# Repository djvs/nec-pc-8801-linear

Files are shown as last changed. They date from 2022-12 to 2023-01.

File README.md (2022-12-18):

# necpc8801linear

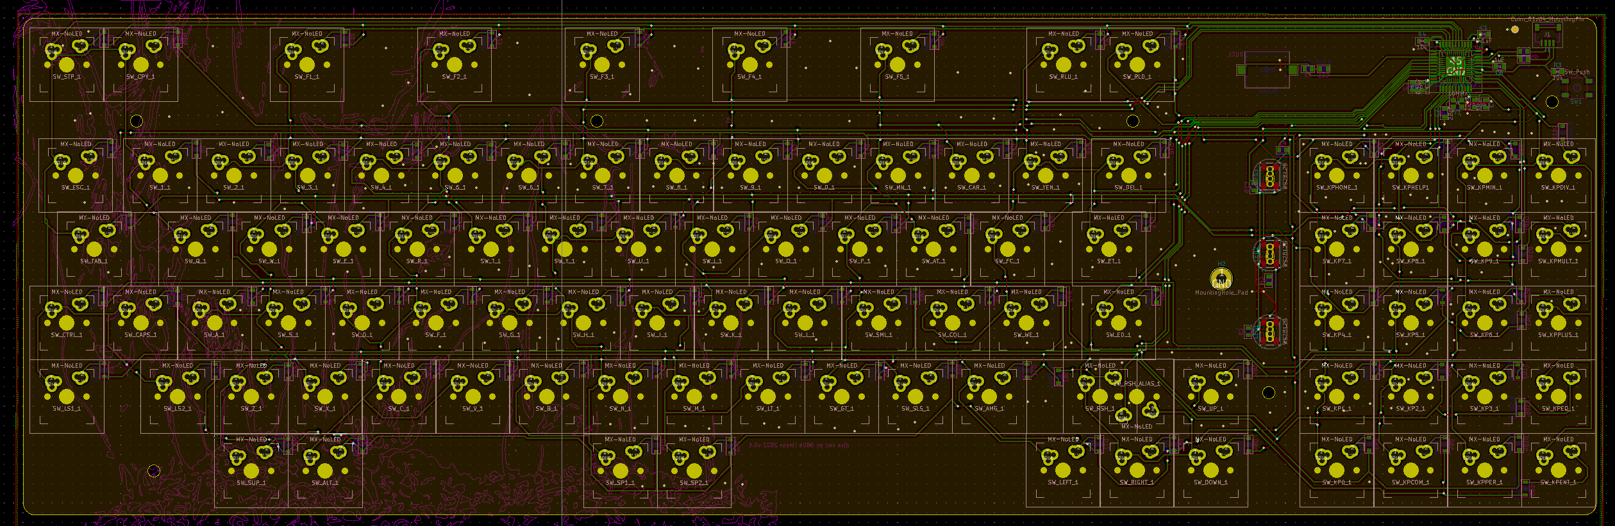
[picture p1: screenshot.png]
Screenshot of PCB


USB/QMK atmega32u4 pcb for NEC PC 8801 (NEC vintage linear and possibly equivalent SMK) with added MX and Alps support.  Also with WS2812B addressable LED & buzzer support.  

Released without warranty, use at your own risk.  Check your layout carefully too.

PRs & feedback welcome!

---

Dimensions: 405mm x 135.5mm

---

Shield: [][cc-by-sa]

This work is licensed under a
[Creative Commons Attribution-ShareAlike 4.0 International License][cc-by-sa].

[][cc-by-sa]

[cc-by-sa]: http://creativecommons.org/licenses/by-sa/4.0/
[cc-by-sa-image]: https://licensebuttons.net/l/by-sa/4.0/88x31.png
[cc-by-sa-shield]: https://img.shields.io/badge/License-CC%20BY--SA%204.0-lightgrey.svg

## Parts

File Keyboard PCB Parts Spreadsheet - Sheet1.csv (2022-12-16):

Part Name | Part Type | Value | Footprint | Digikey Part Num. | LCSC Part Num. | JLCSMT Type | Other Notes
nSMD050-24V | PTC Resettable Fuse | 500mA | 1206 |  | C70076 | Extended
1206L050/15YR | Polyfuse | 500mA Hold / 1A Trip | 1206 |  | C151162 | Extended | The fuse listed in the tutorial doesn't appear to be available, but this one is.
0603WAF220JT5E | Resistor | 22 | 0603 |  | C23345 | Basic
0603WAF1001T5E | Resistor | 1k | 0603 |  | C21191 | Basic
0603WAF5101T5E | Resistor | 5.1k | 0603 |  | C23186 | Basic
0603WAF1002T5E | Resistor | 10k | 0603 |  | C25804 | Basic
0603WAF3302T5E | Resistor | 33k | 0603 |  | C4216 | Basic
0603WAF1003T5E | Resistor | 100k | 0603 |  | C25803 | Basic
0603WAF1004T5E | Resistor | 1M | 0603 |  | C22935 | Basic
CL10C220JB8NNNC | Capacitor, Ceramic | 22pF | 0603 |  | C1653 | Basic
0603B472K500NT | Capacitor, Ceramic | 4.7nF | 0603 |  | C53987 | Basic
CC0603KRX7R9BB104 | Capacitor, Ceramic | 0.1uF | 0603 |  | C14663 | Basic
CL10A105KB8NNNC | Capacitor, Ceramic | 1uF | 0603 |  | C15849 | Basic
CL10A475KO8NNNC | Capacitor, Ceramic | 4.7uF | 0603 |  | C19666 | Basic
CL10A106KP8NNNC | Capacitor, Ceramic | 10uF | 0603 |  | C19702 | Basic
CL10A226MQ8NRNC | Capacitor, Ceramic | 22uF | 0603 |  | C59461 | Basic
0603WAF4701T5E | Resistor | 4.7k | 0603 |  | C23162 | Basic
0805W8F220JT5E | Resistor | 22 | 0805 |  | C17561 | Basic
0805W8F1001T5E | Resistor | 1k | 0805 |  | C17513 | Basic
0805W8F5101T5E | Resistor | 5.1k | 0805 |  | C27834 | Basic
0805W8F1002T5E | Resistor | 10k | 0805 |  | C17414 | Basic
0805W8F3302T5E | Resistor | 33k | 0805 |  | C17633 | Basic
0805W8F1003T5E | Resistor | 100k | 0805 |  | C17407 | Basic
0805W8F1004T5E | Resistor | 1M | 0805 |  | C17514 | Basic
CL21C220JBANNNC | Capacitor, Ceramic | 22pF | 0805 |  | C1804 | Basic
0805B472K500NT | Capacitor, Ceramic | 4.7nF | 0805 |  | C1744 | Basic
CC0805KRX7R9BB104 | Capacitor, Ceramic | 0.1uF | 0805 |  | C49678 | Basic
CL21B105KBFNNNE | Capacitor, Ceramic | 1uF | 0805 |  | C28323 | Basic
CL21A475KAQNNNE | Capacitor, Ceramic | 4.7uF | 0805 |  | C1779 | Basic
CL21A106KAYNNNE | Capacitor, Ceramic | 10uF | 0805 |  | C15850 | Basic
CL21A226MAQNNNE | Capacitor, Ceramic | 22uF | 0805 |  | C45783 | Basic
0805W8F4701T5E | Resistor | 4.7k | 0805 |  | C17673 | Basic | Used by split boards w/ QMK
PJ-320A | TRRS Connector, 3.5mm, THT |  | 3.5-4P |  | --- | Unavailable | Many colors available on Taobao
ATMEGA32U2-AU | Microcontroller | AVR | 32-TQFP (7x7) | ATMEGA32U2-AU-ND | C618733 | Unavailable
ATMEGA32U2-MU | Microcontroller | AVR | 32-VQFN (5x5) | ATMEGA32U2-MU-ND | C57345 | Extended
X322516MLB4SI | Crystal Oscillator | 16MHz | 3225 |  | C13738 | Basic
TS-1186D-C-A | Push Button |  | 4.70mm x 3.50mm |  | C397351 | Unavailable | Side-actuated tactile switch
ATMEGA32U4-AU | Microcontroller | AVR | 44-TQFP (10x10) | ATMEGA32U4-AU-ND | C44854 | Extended
ATMEGA32U4-MU | Microcontroller | AVR | 44-VQFN (7x7) | ATMEGA32U4-MU-ND | C112161 | Extended
STM32F072CBT6 | Microcontroller | ARM/STM32 | 48-LQFP (7x7) | 497-14645-ND | C81720 | Extended
STM32F072CBU6 | Microcontroller | ARM/STM32 | 48-UFQFPN (7x7) | 497-14646-ND | C92504 | Extended
TS-1187A-B-A-B | Push Button |  | 5.1 x 5.1 MM |  | C318884 | Extended
TAJB107K006RNJ | Capacitor, Tantalum | 100uF | CASE-B / 3528 |  | C16133 | Basic
EC11K1525413 | Encoder |  | EC11E |  | C470752 | Unavailable | "Best" normal encoder with detents
EC11E1834403 | Encoder |  | EC11E |  | C361165 | Unavailable | Highest pulse EC11E w/o detents, 1.5mm switch
EC11E15244B2 | Encoder |  | EC11E |  |  | Unavailable | 30 detent (highest reliable) EC11E, 1.5mm switch
TYPE-C-31-M-12 | USB-C |  | HRO-TYPE-C-31-M-12 |  | C165948 | Unavailable | Cheap popular easy to solder USB 2.0 USB-C connector, even cheaper clones available in bulk from aliexpress at around 15c/each, shipped, https://www.aliexpress.com/item/4000259156096.html
TYPE-C-31-M-13 | USB-C |  | HRO-TYPE-C-31-M-13 |  | C223906 | Unavailable | mid-mount version of M-12
TYPE-C-31-M-14 | USB-C |  | HRO-TYPE-C-31-M-14 |  | C223907 | Unavailable | Mid mount version USB-C - Used on the unsplit
DY-S352818/RGBC/6812-2T | LED |  | SK6812 Mini-E |  | C524051 | Unavailable | Tested and seems to work same as a SK6812 Mini-E
SM4007PL | Diode, Standard |  | SOD-123 |  | C64898 | Basic | cheapest diode on jlcpcb, price fluctuates but <$0.004 (at 200+) each
1N4148W | Diode, Standard |  | SOD-123 |  | C81598 | Basic | Common diode
RB060M-60 | Schottky Barrier Diode |  | SOD-123 |  | C115330 | Extended
SMF9.0CA | Bidirectional TVS Diode | 9V Breakdown | SOD-123 |  | C123799 | Extended
SMF6.0CA | Bidirectional TVS Diode | 6V Breakdown | SOD-123 |  | C123791 | Extended
UET14A05L03 | ESD Protection IC |  | SOT-143 |  | C78442 | Extended | Equivalent to PRTR5V0U2X but available as extended part for assembly
PRTR5V0U2X,215 | ESD Protection IC |  | SOT-143B | 1727-3884-2-ND | C12333 | Unavailable | USB data line ESD protection
XC6206P332MR | LDO | 3.3V | SOT-23 |  | C5446 | Basic | 3.3v 200mA LDO stable with ceramic caps and basic JLC part https://datasheet.lcsc.com/szlcsc/1809201513_Torex-Semicon-XC6206P332MR_C5446.pdf
DTC123JKAT146 | Transistor, NPN, Pre-Biased | DTC123J | SOT-23 |  | C111724 | Extended
AO3400A | MOSFET, N-Channel | 30V 5.7A | SOT-23 |  | C347475 | Extended
BSS138LT1G | MOSFET, N-Channel | 50V 200mA | SOT-23 |  | C82045 | Extended | Often used for level shifting
AO3400A | MOSFET, N-Channel | 30V 5.7A | SOT-23-3L |  | C20917 | Basic
SRV05-4-P-T7 | ESD Protection IC | 4 I/Os | SOT-23-6 |  | C85364 | Basic | basic part esd protection for usb https://datasheet.lcsc.com/szlcsc/1809192313_ProTek-Devices-SRV05-4-P-T7_C85364.pdf

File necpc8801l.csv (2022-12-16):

Id | Designator | Footprint | Quantity | Designation | Supplier and ref
1 | SW_Z_1,SW_Y_1,SW_YEN_1,SW_X_1,SW_W_1,SW_WE_1,SW_V_1,SW_U_1,SW_UP_1,SW_T_1,SW_TAB_1,SW_S_1,SW_SUP_1,SW_STP_1,SW_SP2_1,SW_SP1_1,SW_SMI_1,SW_SLS_1,SW_R_1,SW_RSH_ALIAS_1,SW_RSH_1,SW_RLU_1,SW_RLD_1,SW_RIGHT_1,SW_Q_1,SW_P_1,SW_O_1,SW_N_1,SW_M_1,SW_MN_1,SW_L_1,SW_LT_1,SW_LS2_1,SW_LS1_1,SW_LEFT_1,SW_K_1,SW_KPPLUS_1,SW_KPPER_1,SW_KPMULT_1,SW_KPMIN_1,SW_KPHOME_1,SW_KPHELP1,SW_KPEQ_1,SW_KPENT_1,SW_KPDIV_1,SW_KPCOM_1,SW_KP9_1,SW_KP8_1,SW_KP7_1,SW_KP6_1,SW_KP5_1,SW_KP4_1,SW_KP3_1,SW_KP2_1,SW_KP1_1,SW_KP0_1,SW_J_1,SW_I_1,SW_H_1,SW_G_1,SW_GT_1,SW_F_1,SW_FC_1,SW_F5_1,SW_F4_1,SW_F3_1,SW_F2_1,SW_F1_1,SW_E_1,SW_ET_1,SW_ESC_1,SW_ED_1,SW_D_1,SW_DOWN_1,SW_DEL_1,SW_C_1,SW_CTRL_1,SW_CPY_1,SW_COL_1,SW_CAR_1,SW_CAPS_1,SW_B_1,SW_A_1,SW_AT_1,SW_AMG_1,SW_ALT_1,SW_9_1,SW_8_1,SW_7_1,SW_6_1,SW_5_1,SW_4_1,SW_3_1,SW_2_1,SW_1_1,SW_0_1 | mx-nec-alps | 96 | MX-NoLED
2 | LED1,LED2,LED3 | WS2812BDual | 3 | WS2812B
3 | H2 | MountingHole_2.7mm_M2.5_Pad | 1 | MountingHole_Pad
4 | SW1 | SKQG-1155865 | 1 | SW_Push
5 | D16,D1,D2,D3,D4,D5,D6,D7,D8,D9,D10,D12,D13,D14,D15,D17,D18,D19,D20,D21,D23,D24,D25,D26,D27,D28,D29,D30,D31,D32,D34,D35,D36,D37,D38,D39,D40,D41,D42,D44,D45,D46,D47,D48,D49,D50,D51,D52,D53,D54,D56,D57,D58,D59,D60,D61,D62,D63,D64,D65,D67,D68,D69,D70,D71,D72,D73,D75,D76,D78,D81,D82,D83,D84,D85,D89,D90,D91,D92,D93,D94,D95,D96,D97,D99,D101,D102,D103,D104,D109,D110,D98,D106,D105,D43 | D_SOD-123 | 95 | D_Small
6 | C8,C9,C10,C1,C2,C5,C11 | C_0805_2012Metric | 7 | 0.1uF
7 | R1 | R_0805_2012Metric | 1 | 330
8 | C6 | C_0805_2012Metric | 1 | 1uF
9 | C7 | C_0805_2012Metric | 1 | 10uF
10 | J1 | JST_SH_SM04B-SRSS-TB_1x04-1MP_P1.00mm_Horizontal | 1 | Conn_01x04_MountingPin
11 | R3,R4 | R_0805_2012Metric | 2 | 10k
12 | U1 | atmega32u4-mu-and-au | 1 | ATmega32U4-MU
13 | Y1 | Crystal_SMD_3225-4Pin_3.2x2.5mm | 1 | 16MHz
14 | C3,C4 | C_0805_2012Metric | 2 | 22pF
15 | R5,R2,R6 | R_0805_2012Metric | 3 | 22
16 | BUZ1 | Buzzer_Mallory_AST1109MLTRQ | 1 | Buzzer

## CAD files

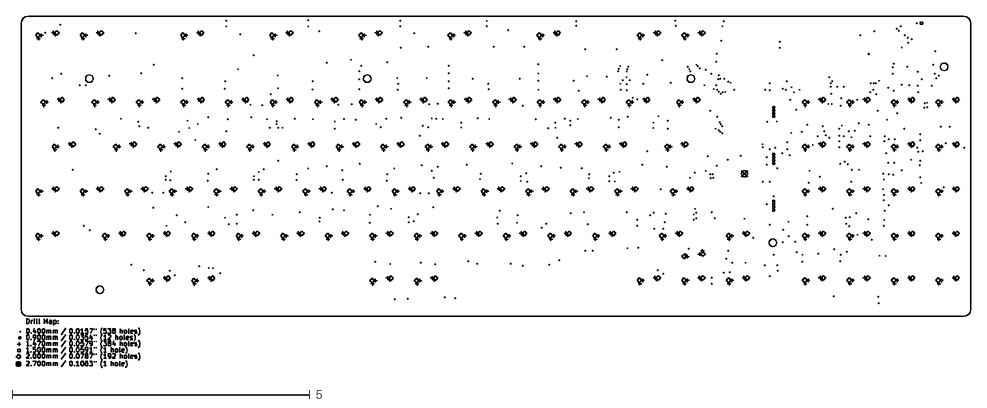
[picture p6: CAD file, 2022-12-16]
outputs/gerber/necpc8801l-PTH-drl_map.dxf
16.0 x 5.90

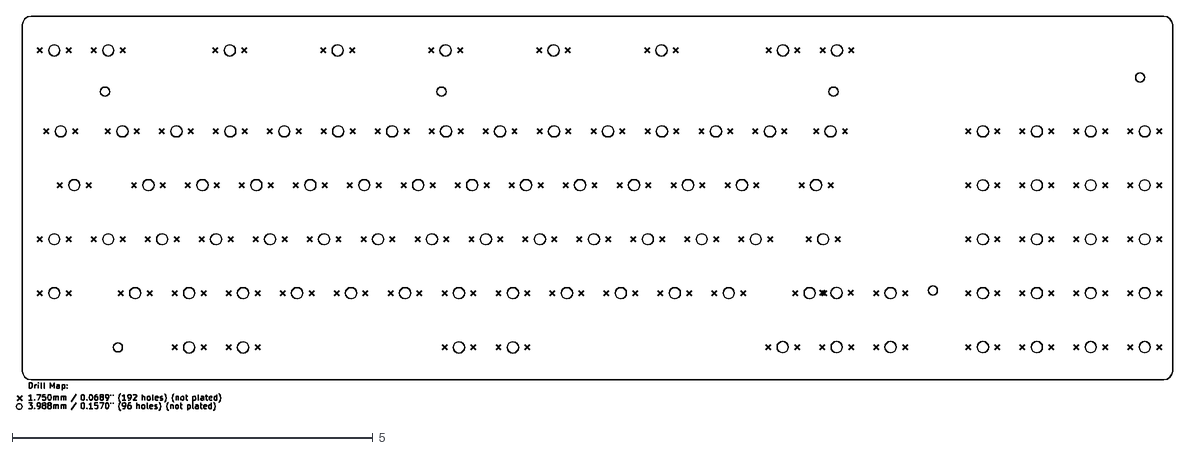
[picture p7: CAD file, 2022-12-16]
outputs/gerber/necpc8801l-NPTH-drl_map.dxf
16.0 x 5.47

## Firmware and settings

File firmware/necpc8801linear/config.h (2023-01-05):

/*
Copyright 2021 djvs

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
You should have received a copy of the GNU General Public License
along with this program.  If not, see <http://www.gnu.org/licenses/>.
*/

#pragma once

#include "config_common.h"

/* USB Device descriptor parameter */
#define VENDOR_ID 0x1209
#define PRODUCT_ID 0x9209
#define DEVICE_VER 0x0001
#define MANUFACTURER "djvs"
#define PRODUCT "necpc8801linear"

/* key matrix size */
#define MATRIX_ROWS 10
#define MATRIX_COLS 10
#define RGBLIGHT_LAYERS

#define AUDIO_PIN C6
/*
 * Keyboard Matrix Assignments
 *
 * Change this to how you wired your keyboard
 * COLS: AVR pins used for columns, left to right
 * ROWS: AVR pins used for rows, top to bottom
 * DIODE_DIRECTION: COL2ROW = COL = Anode (+), ROW = Cathode (-, marked on
 * diode) ROW2COL = ROW = Anode (+), COL = Cathode (-, marked on diode)
 *
 */
#define MATRIX_ROW_PINS \
  { F1, B3, B7, B5, D5, D3, D6, D1, D0, B2 }
#define MATRIX_COL_PINS \
  { F0, F4, F6, F7, F5, D7, B6, B4, D2, B0 }
#define UNUSED_PINS \
  { E6, C7, B1 }

/* COL2ROW, ROW2COL */
#define DIODE_DIRECTION COL2ROW

/*
 * Split Keyboard specific options, make sure you have 'SPLIT_KEYBOARD = yes' in
 * your rules.mk, and define SOFT_SERIAL_PIN.
 */
// #define SOFT_SERIAL_PIN D0  // or D1, D2, D3, E6

//#define LED_NUM_LOCK_PIN B0
//#define LED_CAPS_LOCK_PIN B1
//#define LED_SCROLL_LOCK_PIN B2
//#define LED_COMPOSE_PIN B3
//#define LED_KANA_PIN B4

//#define BACKLIGHT_PIN F4
//#define BACKLIGHT_CAPS_LOCK
//#define BACKLIGHT_DRIVER =
//#define BACKLIGHT_LEVELS 3
//#define BACKLIGHT_BREATHING

#define RGB_DI_PIN D4
#ifdef RGB_DI_PIN
#define RGBLED_NUM 3
#define RGBLIGHT_DEFAULT_MODE (RGBLIGHT_MODE_RAINBOW_SWIRL)

#define RGBLIGHT_DEFAULT_HUE 64
//#    define RGBLIGHT_DEFAULT_SAT 255
#define RGBLIGHT_DEFAULT_VAL 255
//#    define RGBLIGHT_HUE_STEP 8
//#    define RGBLIGHT_SAT_STEP 8
//#    define RGBLIGHT_VAL_STEP 8
//#    define RGBLIGHT_LIMIT_VAL 255 /* The maximum brightness level */
//#    define RGBLIGHT_SLEEP  /* If defined, the RGB lighting will be switched
//off when the host goes to sleep */
/*== all animations enable ==*/
#define RGBLIGHT_ANIMATIONS
/*== or choose animations ==*/
//#    define RGBLIGHT_EFFECT_BREATHING
//#    define RGBLIGHT_EFFECT_RAINBOW_MOOD
//#    define RGBLIGHT_EFFECT_RAINBOW_SWIRL
//#    define RGBLIGHT_EFFECT_SNAKE
//
//#    define RGBLIGHT_EFFECT_KNIGHT
//#    define RGBLIGHT_EFFECT_CHRISTMAS
//#    define RGBLIGHT_EFFECT_STATIC_GRADIENT
//#    define RGBLIGHT_EFFECT_RGB_TEST
//#    define RGBLIGHT_EFFECT_ALTERNATING
/*== customize breathing effect ==*/
/*==== (DEFAULT) use fixed table instead of exp() and sin() ====*/
//#    define RGBLIGHT_BREATHE_TABLE_SIZE 256      // 256(default) or 128 or 64
/*==== use exp() and sin() ====*/
//#    define RGBLIGHT_EFFECT_BREATHE_CENTER 1.85  // 1 to 2.7
//#    define RGBLIGHT_EFFECT_BREATHE_MAX    255   // 0 to 255
#endif

/* Debounce reduces chatter (unintended double-presses) - set 0 if debouncing is
 * not needed */
#define DEBOUNCE 5

/* define if matrix has ghost (lacks anti-ghosting diodes) */
//#define MATRIX_HAS_GHOST

/* Mechanical locking support. Use KC_LCAP, KC_LNUM or KC_LSCR instead in keymap
 */
#define LOCKING_SUPPORT_ENABLE
/* Locking resynchronize hack */
#define LOCKING_RESYNC_ENABLE

/* If defined, GRAVE_ESC will always act as ESC when CTRL is held.
 * This is useful for the Windows task manager shortcut (ctrl+shift+esc).
 */
//#define GRAVE_ESC_CTRL_OVERRIDE

/*
 * Force NKRO
 *
 * Force NKRO (nKey Rollover) to be enabled by default, regardless of the saved
 * state in the bootmagic EEPROM settings. (Note that NKRO must be enabled in
 * the makefile for this to work.)
 *
 * If forced on, NKRO can be disabled via magic key (default = LShift+RShift+N)
 * until the next keyboard reset.
 *
 * NKRO may prevent your keystrokes from being detected in the BIOS, but it is
 * fully operational during normal computer usage.
 *
 * For a less heavy-handed approach, enable NKRO via magic key (LShift+RShift+N)
 * or via bootmagic (hold SPACE+N while plugging in the keyboard). Once set by
 * bootmagic, NKRO mode will always be enabled until it is toggled again during
 * a power-up.
 *
 */
//#define FORCE_NKRO

/*
 * Feature disable options
 *  These options are also useful to firmware size reduction.
 */

/* disable debug print */
//#define NO_DEBUG

/* disable print */
//#define NO_PRINT

/* disable action features */
//#define NO_ACTION_LAYER
//#define NO_ACTION_TAPPING
//#define NO_ACTION_ONESHOT

/* disable these deprecated features by default */
#define NO_ACTION_MACRO
#define NO_ACTION_FUNCTION

/* Bootmagic Lite key configuration */
//#define BOOTMAGIC_LITE_ROW 0
//#define BOOTMAGIC_LITE_COLUMN 0

#define DYNAMIC_KEYMAP_LAYER_COUNT 2

#ifdef AUDIO_ENABLE
  #define STARTUP_SONG SONG(CAMPANELLA)
#endif

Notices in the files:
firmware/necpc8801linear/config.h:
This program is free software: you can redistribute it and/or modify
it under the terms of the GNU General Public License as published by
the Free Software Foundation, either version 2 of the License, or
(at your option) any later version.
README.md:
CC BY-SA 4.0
